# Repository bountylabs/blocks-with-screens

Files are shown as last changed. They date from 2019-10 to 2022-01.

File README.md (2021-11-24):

# Blocks With Screens

 

Block in its natural habitatAnimated 3d blockPuzzle-style block

It's Twitterversary blocks, but with screens and internet. Originally a Fall 2019 Twitter HackWeek project by [@johnboiles](https://github.com/johnboiles), [@magus](https://github.com/magus), [@mikeperiscope](https://github.com/mikeperiscope), [@seanfchan](https://github.com/seanfchan), and [@smartfuse](https://github.com/smartfuse).

## Assembly

### [**Click here to view assembly instructions on YouTube**](https://youtu.be/LxgdhXQPZw0)

<a href="https://youtu.be/LxgdhXQPZw0" target="_blank">
  assembly-video-thumbnail
</a>

Tips, notes & corrections:
* To protect the pins, we're shipping with two of the circuit boards attached to eachother. You'll need to separate these circuit boards before following the instructions above. Just gently pull them apart to separate them. They're hard to break :)
* Some of the boards may have small tabs protruding from the sides which may cause them not to fit in the wooden block. This is a byproduct of the manufacturing process. Clip these tabs off with nail clippers or wire clippers.
* Feel free to ask us on Twitter [@blkswithscreens](https://twitter.com/blkswithscreens) if you have any questions or problems!

## Components

### Blockware

This is the example software that you can run on the blocks. See [blockware/README.md](https://github.com/bountylabs/blocks-with-screens/blob/main/blockware/README.md) for installation instructions and a listing (with gifs!) of the available blockware.

### CAD

This contains the various design files building the block hardware. Most importantly, it contains the [Autodesk Eagle](https://www.autodesk.com/products/eagle/free-download) design files for the 3 PCBs that make up the block. See the [README.md](https://github.com/bountylabs/blocks-with-screens/blob/main/cad/pcb/README.md) in that directory for an overview of the responsibilities of the three different boards.

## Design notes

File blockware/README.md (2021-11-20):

# Blockware

A collection of programs meant to run on the blocks.

## Table of contents
- [Getting Started](#getting-started)
- [PlatformIO CLI](#using-the-platformio-cli)
- [Protips](#protips)
- [Demos](#demo-blockwares)

## Getting Started

All of these blockwares are configured to be compiled and uploaded using [PlatformIO](https://platformio.org/). You can probably also use the Arduino IDE or any other tool that works to compile and upload Arduino-compatible code with ESP8266 processors.

The easiest way to get started is using **[Visual Studio Code (VSCode)](https://code.visualstudio.com)** with the **[PlatformIO extension](https://platformio.org/install/ide?install=vscode)**.

1. Install **VSCode** either from the [website](https://code.visualstudio.com/) or (on macOS) using Homebrew `brew cask install visual-studio-code`.
    - **Windows Only** You may need to install drivers for your computer to be able to communicate with the block. [See below](#windows_drivers)
2. With VSCode open select **View -> Extensions** and search for `PlatformIO IDE`.
3. Click the extension and click **Install**.

    PlatformIO IDE Instructions

4. `File -> Open Workspace...` and select the `workspace.code-workspace` file in one of the blockware folders (e.g. `blockware/curvy-snake`)

    **_NOTE_**: In the workspace, you should have the **PlatformIO actions** available at the bottom of your VSCode

    VSCode PlatformIO Toolbar

  5. Connect your block to the computer using a Micro USB cable
  6. Turn it on using the switch in the back
  7. Press the **Upload** button (looks like a right arrow) in the Platform IO actions (bottom of your VSCode)

     NOTE: The program should compile and then upload to your block. It can also be handy to use the Serial Monitor to view any logs from the program that are output over the USB serial port.

     If the upload fails with an error message like `Error: Please specify upload_port for environment` or `Timed out waiting for packet header`, then you may need to edit the [`platformio.ini`](https://github.com/bountylabs/blocks-with-screens/blob/main/blockware/curvy-snake/platformio.ini) in the blockware's directory to set a specific `upload_port`. Look in `/dev/` for a `tty` device named something like `usbserial` or `ttyUSB` or `wchusbserial` and change `upload_port` to match the path to that device exactly.

  8. That's it, you should see the demo running on your block!

     For more info on using the PlatformIO VSCode extension check out the [PlatformIO Quick Start guide](https://docs.platformio.org/en/latest/integration/ide/vscode.html#quick-start).

## Using the PlatformIO CLI

You can alternately use the PlatformIO CLI if that's more your style. Follow one of the [installation methods on the PlatformIO site](https://platformio.org/install/cli). As of this writing, they recommend using their installer script:

```bash
python3 -c "$(curl -fsSL https://raw.githubusercontent.com/platformio/platformio/master/scripts/get-platformio.py)"
```

The script will probably instruct you to add something to your `PATH` in order to use the `pio` binary. Something like the following (which you could add to your `.bashrc` / `.zshrc`)

```bash
export PATH=$HOME/.platformio/penv/bin:$PATH
```

You can now build and upload blockware from the command line like this:

```bash
cd blockware/curvy-snake
pio run --target upload
```

Or if you want to override the `upload_port` (e.g. for blockwares that support WiFi OTA programming)

```bash
cd blockware/gif-download
pio run --target upload --upload-port gif-example.local
```

## Protips

#### Serial Monitor Reset

In the VSCode PlatformIO Serial Monitor, you can quickly restart the block by pressing `Ctrl-T Ctrl-D` twice. This toggles the `DTR` pin on the USB-serial chip and that pin is connected to the `RST` pin on the microcontroller.

#### Logging using `Dlog.h`

If using the `DLog` library for logging over the serial monitor or telnet you need to add `#define SERIALLOG 1` or `#define TELNETLOG 1` respectively before including `DLog.h` to enable serial logging. For example, for logging to the serial port:

```C
#define SERIALLOG 1
#include <DLog.h>
```

If using `TELNETLOG` then from your computer you can do something like the following to get the logs to your terminal over the network.

```bash
telnet homeassistant-display.local
```

#### Ensure PlatformIO is up to date

- Open the VSCode PlatformIO CLI (`⌘ + Shift + P` type `platformio cli` and press `Enter`)
- In the TERMINAL window at the bottom of VSCode, type in the command below

```sh
make update
```

Your PlatformIO dependencies should not all be up to date. Running the command again will report each at `[Up-to-date]` 🎉

## Demo Blockwares

This repo contains a handful of example blockwares you could run directly or use as a starting point to make your own blockware! Please share back any neat things you make so that others can benefit from it!

### Adafruit Example

adafruit-example

A fork of Adafruit's [SSD1351 OLED example code](https://github.com/adafruit/Adafruit-SSD1351-library/blob/master/examples/test/test.ino) with the `delay`s removed. Useful as an overview of the available graphics APIs in the Adafruit GFX library or as a graphics benchmark when tweaking the Adafruit GFX Library code.

### Bouncing Logo

Bouncing Logo

The most 90s-est demo we've got. Bounce the Twitter logo around your screen just like your DVD player did to prevent burn-in on your CRT TV in 1999.

### Curvy Snake

curvy-snake

It's kinda like those old pipes screensavers, or snake with curves. Watch randomly generated curves snake around your block's screen.

### Gif Download

Gif DownloadServer Interface

This demo shows a QR code that takes you to a web page where you can upload a gif, have it translated to a block-friendly format, then the block can download it and begin to display it.

Requires a Node.js-based server component which you can find in in the `gif-download/server` directory.

### Homeassistant Display

Home Assistant Display

An example of a program that can connect to a [Home Assistant](https://www.home-assistant.io/) home automation interface and display sensor values on the screen.

### JPEG Download Example

JPEG Download

An example that downloads a JPEG and displays it on the block.

### Pixel Dust

pixel-dust

An example that uses the [Adafruit Pixel Dust](https://github.com/adafruit/Adafruit_PixelDust) to create animated dust that interacts with the accelerometer and a static Twitter Logo.

### RGB LED

rgb-led

An example that uses the (normally not-included) internal RGB LED. This requires modification of the PCB by soldering on an RGB LED. This is probably not the blockware you're looking for.

### Snake

Snake introGameplayUser Interface

The game of snake! This demo creates a WiFi access point that you can connect to on your phone to control the snake.

### Stocks and Weather

Stocks and Weather

An example that downloads stocks and weather.

### Video Display

An example of real-time video streaming from your computer to your block.

<a href="https://twitter.com/samhaves/status/1177639088540635141">Blockware Live Video Demo</a>

### Windows Drivers

Since the PCB is compatible with a [Wemos D1 Mini](https://docs.wemos.cc/en/latest/d1/d1_mini.html) use the [following CH340 driver](https://docs.wemos.cc/en/latest/ch340_driver.html).
  
- With your block plugged in to your computer, find it in the device manager
  - Windows Device Manager
- Double click on the device
  - Windows USB Device
- Click on the Driver tab and choose Update Driver
  - Windows Driver Update
- Browse to where you downloaded and unzipped the driver
  - Browse for Driver
- Let Windows find the driver files within the folder or subfolder
  - Browse for Driver

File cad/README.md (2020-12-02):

# CAD Files

This contains the various design files for the mechanical components of the blocks.

## Parts List
* Assembled PCBs (See the README.md in the `pcb` directory in the repository for more details)
  * USB board
  * Microcontroller board
  * OLED board
* 1.5” SSD1351 128x128 OLED screen
* 240mAh 602025 LiPo battery with JST-SH connector
* Laser-cut wood “puzzle” blocks (5 separate pieces that fit together)
* Laser cut paper spacers (for friction fit and alignment)

## Components

### PCBs

The most important part of the block! The `pcb` directory contains the [Autodesk Eagle](https://www.autodesk.com/products/eagle/free-download) design files for the 3 PCBs that make up the block. See the [README.md](https://github.com/bountylabs/blocks-with-screens/blob/main/cad/pcb/README.md) in that directory for an overview of the responsibilities of the three different boards.

### Laser-cut Wood “Puzzle” Blocks

These are the laser-cuttable sides and back of the block. Since these need to fit together with only friction, the design may need to be adjusted based on the laser being used. Designs are included for a 0.23mm kerf laser as well as ones that worked well on @johnboiles's GlowForge. The `puzzleblock.f3d` (Fusion 360) file has the original designs.

### Laser-cut Paper Spacers

These help hold the PCBs inside the block and also helps center them inside the block. These should be cut out of 110 lb card stock paper. The laser width doesn’t matter here since paper bends.

### Block With Screen F3Z File

This Fusion 360 file has all of the components modeled in one place. Used mostly for neat visualizations like the assembly video. Also very useful to visualize the internal spacing when changing PCB components placements. This also contains the original design for the paper spacers.

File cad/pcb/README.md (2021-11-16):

# Blocks With Screens PCB Files

## Components

The blocks are made up of 3 components.

### OLED Board

OLED Back OLED Front

This board is responsible for all the circuitry to drive a SSD1351 OLED display. This design is heavily based on [Adafruit's breakout board](https://github.com/adafruit/Adafruit-1.5inch-Color-OLED-PCB) for the same display.

It consists of a 13V boost regulator to provide the required voltage to drive the OLED, as well as necessary passive components required by the OLED's datasheet.

### Microcontroller Board

Microcontroller Back Microcontroller Front

This board is a mounting point for the ESP12 microcontroller and the MMA8452Q 3-axis accelerometer. It also has unpopulated pads for a [SparkFun Qwiic](https://www.sparkfun.com/qwiic) connector and a WS2812B RGB LED if you want to add additional functionality.

### USB Board

USB Back USB Front

This board is responsible for:
* Providing a USB serial interface for programming the microcontroller (with automatic reset)
* Providing regulated 3.3V power to the Microcontroller and OLED
* Providing charging circuitry to charge the LiPo battery

This board is based on various Adafruit [LiPo charging boards](https://learn.adafruit.com/adafruit-pro-trinket-lipoly-slash-liion-backpack) and [USB powered boards](https://learn.adafruit.com/introducing-trinket/downloads) with the simplest (by part count) USB-serial chip we could find.

## PCB Hacking

We hope you'll open up your blocks and add new functionality or boards we never even dreamed of.

The pin layout is compatible with the [Wemos D1 Mini](https://docs.wemos.cc/en/latest/d1/d1_mini.html) (available on your usual internet shopping sites) so any shields made for those should work!

There is un unpopulated [SparkFun Qwiic](https://www.sparkfun.com/qwiic) connector on the microcontroller board. If you solder on a Qwiic connector (just a 4-pin JST connector) you can connect your board to any of the dozens of [Qwiic compatible peripherals](https://www.sparkfun.com/qwiic#products) (e.g. sensors, screens, GPS) out there.

There's an unpopulated spot on the Microcontroller board for a WS2812B RGB LED (or similar). This might come in handy if you want to, say, cut a window in the side of your block and trick it out with colors inside. Note that these LEDs will typically initialize to a random color so if you add the LED, but don't use it in your program, it will probably be lit up to a random color.

You could also add PCBs for different microcontrollers, different screens, or maybe even make a USB-C version! This was meant to be modular. Have fun, and share back what you build!

## Manufacturing Boards

We used [OshPark](https://oshpark.com/) for creating our prototype PCBs which we then soldered by hand or in a [reflow oven](https://github.com/UnifiedEngineering/T-962-improvements). We used [PCBWay](https://www.pcbway.com/) to mass manufacture assembled PCBs.

There's an included [script](https://github.com/bountylabs/blocks-with-screens/blob/main/pcb/eagle_to_pcbway.py) for exporting the Eagle PCB files in a bill-of-materials (BOM) format that PCBWay accepts.

## Changelog

### Microcontroller Board V4

* MMA8452QR1 accelerometers are #chipshortage'd. Switch to LIS2DW12

### OLED Board V5

* Revert the revert to go back to VIN for the 13V boost circuit as it didn't seem to have any effect. And this lightens the load on the 3.3V regulator. This is effectively the same design as OLED Board V3.

### USB Board V5

* Turn the battery connector counter-clockwise by 90 degrees to avoid wires hanging off the side of the board and not fitting in the block.

### OLED Board V4

* Revert back to using 3.3V for the 13V boost circuit to hopefully avoid issues I've seen twice now with the OLED screens developing bad vertical lines of pixels. This is what Adafruit does in their board; perhaps there's a reason for it.

### USB Board V4

* Use thicker (power) trace for 3.3V
* Make the USB side slots wider to comply with PCBWay
* Add a JST-SH connector (SM02B-SRSS-TB) for the battery

### Microcontroller Board V3

* Attach 3.3V to the ESP12 (doh!)

### OLED Board V3

* Uses `D4/GPIO2` for `OLED DC` instead of `D1/GPIO5` since that pin is I2C `SCK`.

### Microcontroller Board V2

* Fixed disconnected decoupling capacitor.
* Added optional header for MMA8452QR1 accelerometer.
* Added optional [Qwiic](https://www.sparkfun.com/qwiic) header for SparkFun accessories.
* Added optional [5050 NeoPixel](https://www.adafruit.com/product/1655) pad.

### USB Board V3

* Fix width of power trace going to the switch.

### OLED Board V2

* Uses `D1` for `OLED DC` instead of `D6` (`MISO`) so we don’t have to hack SPI.c for hardware SPI.
* Uses `VIN` for power for the 13V boost (possible this will reduce the flicker, especially during low battery).
* Removed the 3-pin SPI jumper since we didn’t use it.
* Move all the screen capacitors closer to the screen connector (even smaller chance of reducing flicker)

### USB Board V2

* Removed oscillator and move to using the `CH340C` instead of `CH340G` USB-UART chip.
* Connect `VCC` on the `CH340C` chip (fix error from V1).
* Move most parts to the front of the board for easier manufacturing.
* Add an optional on LED.
* Add pads for a switch.

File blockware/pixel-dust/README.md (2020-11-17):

# Pixel Dust

Demo that uses the onboard accelerometer along with [Adafruit's Pixel Dust library](https://github.com/adafruit/Adafruit_PixelDust) to generate a physics demo where particles move with the direction of gravity.

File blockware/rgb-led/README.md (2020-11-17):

# RGB LED Example

Very simple example that uses the (normally unpopulated) SK6812 LED on the Microcontroller board.

Note, this RGB LED *was not* included in the final assembly of the blocks, so this is only available for reference purposes for those brave enough to solder on their own internal RGB LED to the microcontroller board.

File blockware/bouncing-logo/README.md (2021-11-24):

# Bouncing Logo

Bouncing Twitter logo that cycles Twitter colors. Channels 1999 DVD player screensaver vibes

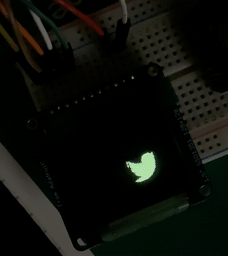
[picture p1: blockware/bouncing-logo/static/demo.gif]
Demo


## Inspiration

### Twitter color palette

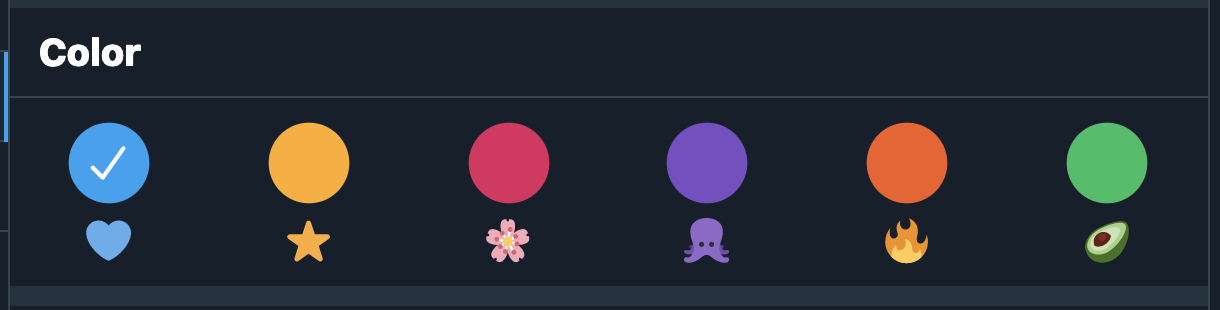
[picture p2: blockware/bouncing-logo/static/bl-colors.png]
ColorPalette


### Bouncing DVD logo concept

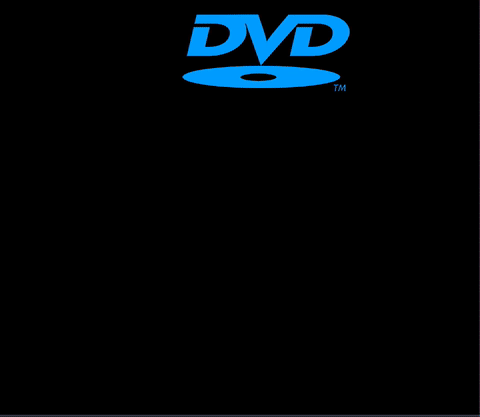
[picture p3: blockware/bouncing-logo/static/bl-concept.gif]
InspirationDVDAnimation


## VirtualBlox support

You can also run this blockware locally using VirtualBlox. Change the env in VSCode to VirtualBlox then hit 'upload'. Or use `pio run -e VirtualBlox -t upload` from the command line.



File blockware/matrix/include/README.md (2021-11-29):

# Why is this folder here?

`blockware/matrix/.vscode/c_cpp_properties.json` keeps including `"blockware/matrix/include",` in the `includePath` array under the `PlatformIO` entry in `configurations`. So we create it to get rid of an annoying error in VSCode

```
⚠️ Cannot find "/Users/noah/github/blocks-with-screens/blockware/matrix/include".
```

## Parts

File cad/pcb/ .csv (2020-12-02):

Part | Value | Device | Package | Description | MPN | POPULATE
C1 | 1.0uF | CAP_CERAMIC0805 | 0805 | Ceramic Capacitors | C0805C105K4RAC7210
C2 | 10uF/16V | CAP_CERAMIC0805 | 0805 | Ceramic Capacitors | EMK212ABJ106KG-T
C3 | 10uF | CAP_CERAMIC0805 | 0805 | Ceramic Capacitors | EMK212ABJ106KG-T
C4 | 10uF/16V | CAP_CERAMIC0805 | 0805 | Ceramic Capacitors | EMK212ABJ106KG-T
C5 | 1.0uF | CAP_CERAMIC0805 | 0805 | Ceramic Capacitors | C0805C105K4RAC7210
C6 | 10uF | CAP_CERAMIC0805 | 0805 | Ceramic Capacitors | EMK212ABJ106KG-T
C7 | 0.1uF | CAP_CERAMIC0805 | 0805 | Ceramic Capacitors | 08051C104J4T4A
D1 | 1N4148 | DIODESOD-323 | SOD-323 | Diode | 1N4148WS-E3-08
D2 | 1N4148 | DIODESOD-323 | SOD-323 | Diode | 1N4148WS-E3-08
D3 | BAT54T1G | DIODESOD-123 | SOD-123 | Diode | BAT54T1G
JP1 |  | PINHD-1X8CLEANBIG | 1X08-CLEANBIG | PIN HEADER | 10129378-908001BLF | 0
JP2 |  | PINHD-1X8CLEANBIG | 1X08-CLEANBIG | PIN HEADER | 10129378-908001BLF | 0
L1 | 10uH | INDUCTOR | INDUCTOR_1007 | Inductors | L0805R100MPWRT
R1 | 10K | R-US_R0805 | R0805 | RESISTOR, American symbol | CRCW080510K0FKEAC
R2 | 600K | R-US_R0805 | R0805 | RESISTOR, American symbol | ERJ-6ENF5903V
R3 | 50 | R-US_R0805 | R0805 | RESISTOR, American symbol | CRCW080550R0FKTA
R4 | 100K | R-US_R0805 | R0805 | RESISTOR, American symbol | CR0805AFX-1003EAS
R5 | 10K | R-US_R0805 | R0805 | RESISTOR, American symbol | CRCW080510K0FKEAC
U1 | UG-2828GDEDF11 | DISP_OLED_UG-2828GDEDF11TOP | FPC_XF2M-3015-1A | 128x128 1.5 RGB OLED - UG-2828GDEDF11" | XF2M-3015-1A
U2 | FAN5331SX | FAN5331 | SOT23-5@1 | FAN5331 - LED/OLED 20V Boost Converter | FAN5331SX

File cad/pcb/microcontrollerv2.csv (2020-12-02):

Part | Value | Device | Package | Description | MPN | POPULATE
C1 | 10uF | C-USC0805 | C0805 | CAPACITOR, American symbol | EMK212ABJ106KG-T
C2 | .1uF | C-USC0805 | C0805 | CAPACITOR, American symbol | 08051C104J4T4A
C3 | 10uF | C-USC0805 | C0805 | CAPACITOR, American symbol | EMK212ABJ106KG-T | 0
C4 | .1uF | C-USC0805 | C0805 | CAPACITOR, American symbol | 08051C104J4T4A | 0
J1 | SMD | I2C_STANDARDJS-1MM | 1X04_1MM_RA | SparkFun I2C Standard Pinout Header | PRT-14417 | 0
JP1 |  | PINHD-1X8CLEANBIG | 1X08-CLEANBIG | PIN HEADER | 8Fx1L-254mm
JP2 |  | PINHD-1X8CLEANBIG | 1X08-CLEANBIG | PIN HEADER | 8Fx1L-254mm
LED1 | WS2812B5050 | WS2812B5050 | WS2812B |  | 1655 | 0
R1 | 10K | R-US_R0805 | R0805 | RESISTOR, American symbol | CRCW080510K0FKEAC
R2 | 10K | R-US_R0805 | R0805 | RESISTOR, American symbol | CRCW080510K0FKEAC
R3 | 10K | R-US_R0805 | R0805 | RESISTOR, American symbol | CRCW080510K0FKEAC
R4 | 10K | R-US_R0805 | R0805 | RESISTOR, American symbol | CRCW080510K0FKEAC
U1 | MMA8452Q | MMA8452Q | QFN-16_0.5MM | MMA8452Q 3-Axis, 12/8-bit Digital Accelerometer | MMA8452QR1 | 0
X1 |  | ESP-12 | ESP-12 |  | ESP12

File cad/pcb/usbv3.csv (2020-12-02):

Part | Value | Device | Package | Description | MPN | PROD_ID | SF_ID | VALUE
C1 | 10µF | C-USC0805 | C0805 | CAPACITOR, American symbol | EMK212ABJ106KG-T
C2 | 10uF | C-USC0805 | C0805 | CAPACITOR, American symbol | EMK212ABJ106KG-T
C3 | 10µF | C-USC0805 | C0805 | CAPACITOR, American symbol | EMK212ABJ106KG-T
C4 | 1.0uF | 1.0UF-0805-25V-10% | 0805 | 1µF ceramic capacitors | C0805C105K4RAC7210 | CAP-08064 |  | 1.0uF
C5 | 0.1uF | 1.0UF-0805-25V-10% | 0805 | 1µF ceramic capacitors | 08051C104J4T4A | CAP-08064 |  | 1.0uF
CHG | RED | LED0805_NOOUTLINE | CHIPLED_0805_NOOUTLINE | LED | SMLD12E3N1WT86
D1 | MBR120 | DIODE-SCHOTTKYSOD-123 | SOD-123 |  | MBR120ESFT1G
J1 | JSTPH | CONN_02 | 1X02 | Multi connection point. Often used as Generic Header-pin footprint for 0.1 inch spaced/style header connections
J2 |  | 614105150621 | 614105150621 | WR-COM_USB_Micro Type AB_Vertical_THT, | 614105150621
JP1 |  | PINHD-1X8CLEANBIG | 1X08-CLEANBIG | PIN HEADER | 8Fx1L-254mm
JP2 |  | PINHD-1X8CLEANBIG | 1X08-CLEANBIG | PIN HEADER | 8Fx1L-254mm
ON | RED | LED0805_NOOUTLINE | CHIPLED_0805_NOOUTLINE | LED | SMLEN3WBC8W1
Q1 | ZXMP6A13FTA | MOSFET-P | SOT23-R | P-Channel Mosfet | ZXMP6A13FTA
Q2 | mmbt2222 | TRANSISTOR_NPNSOT23-3 | SOT23-3 | Transistor NPN | MMBT2222A-G
Q3 | mmbt2222 | TRANSISTOR_NPNSOT23-3 | SOT23-3 | Transistor NPN | MMBT2222A-G
R1 | 100K | R-US_R0805 | R0805 | RESISTOR, American symbol | CR0805AFX-1003EAS
R2 | 1K | R-US_R0805 | R0805 | RESISTOR, American symbol | ESR10EZPJ102
R3 | 10K\ | R-US_R0805 | R0805 | RESISTOR, American symbol | CRCW080510K0FKEAC
R4 | 1K | R-US_R0805 | R0805 | RESISTOR, American symbol | ESR10EZPJ102
R5 | 10K | R-US_R0603 | R0603 | RESISTOR, American symbol | CRCW080510K0FKEAC
R6 | 10K | R-US_R0603 | R0603 | RESISTOR, American symbol | CRCW080510K0FKEAC
S1 |  | SWITCH-SPDT-SMD-AYZ0202 | SWITCH_DPDT_SMD_AYZ0202 | Single Pole, Double Throw (SPDT) Switch | AYZ0202AGRLC | SWCH-08179 | COM-00597
U1 | MIC5225-3.3v | VREG_SOT23-5 | SOT23-5 | SOT23-5 Fixed Voltage Regulators | MIC5225-3.3YM5-TR
U2 | CH340C | CH340C | SO016 |  | CH340C | IC-14038
U3 | MCP73831T-2ACI/OT | MCP73831/OT | SOT23-5L | MCP73831/2 | MCP73831T-2ACI/OT

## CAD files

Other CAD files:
cad/puzzleblock.f3d

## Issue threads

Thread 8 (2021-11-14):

Windows driver installation instructions

leeaustinadams, 2021-11-14:
Although I mainly use Linux, I was messing around on my Windows 10 laptop and noticed some drivers are needed for communication with the board. I'll put a pull request together to add instructions.

johnboiles, 2021-11-16:
Oooh that will be awesome, thanks!!

Closed 2021-11-17.

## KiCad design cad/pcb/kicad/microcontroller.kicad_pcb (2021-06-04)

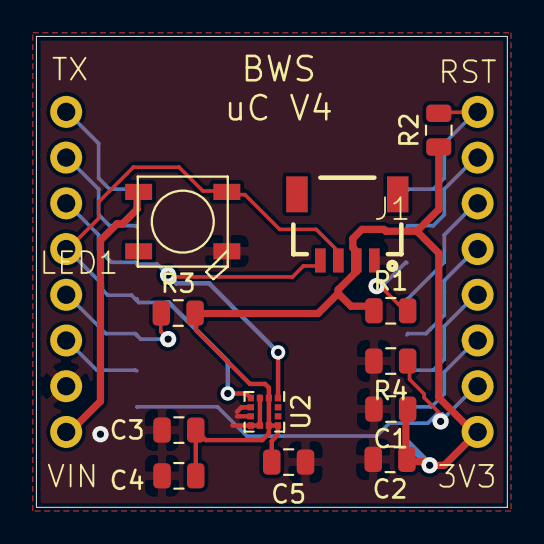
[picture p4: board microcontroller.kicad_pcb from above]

Board: 2 copper layers, 26.2 x 26.2 mm, 15 parts (0 on the bottom side), 17 nets.

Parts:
C1, C4: 10uF; C_0805_2012Metric
C2: .1uF; C_0805_2012Metric
C3, C5: 100nF; C_0805_2012Metric
J1: SMD; 1X04_1MM_RA
JP1, JP2: PINHD-1X8CLEANBIG; 1X08-CLEANBIG
LED1: WS2812B5050; WS2812B
R1, R2, R3, R4: 10K; R_0805_2012Metric
U2: LIS2DW12; LGA-12_2x2mm_P0.5mm
X1: ESP-12

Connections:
3.3V: C1.1, C2.1, C3.2, C4.2, C5.1, J1.2, JP2.1, R1.1, R2.1, R3.2, U2.2, U2.9, U2.10, X1.8
/A0: JP2.7, X1.2
/CH_PD: R1.2, X1.3
/D0/GPIO16: JP2.6, X1.4
/D1/GPIO5/SCL: J1.4, JP1.3, U2.1, X1.14
/D2/GPIO4/SDA: J1.3, JP1.4, LED1.4-DIN, U2.4, X1.13
/D3/GPIO0: JP1.5, R3.1, X1.12
/D4/GPIO2: JP1.6, X1.11
/D5/GPIO14/SCK: JP2.5, X1.5
/D6/GPIO12/MISO: JP2.4, X1.6
/D7/GPIO13/MOSI: JP2.3, X1.7
/D8/GPIO15: JP2.2, R4.1, X1.10
/RESET: JP2.8, R2.2, X1.1
/RX: JP1.2, X1.15
/TX: JP1.1, X1.16
GND: C1.2, C2.2, C3.1, C4.1, C5.2, J1.1, JP1.7, LED1.3-GND, R4.2, U2.3, U2.5, U2.6, U2.7, U2.8, X1.9
VIN: JP1.8, LED1.1-VDD

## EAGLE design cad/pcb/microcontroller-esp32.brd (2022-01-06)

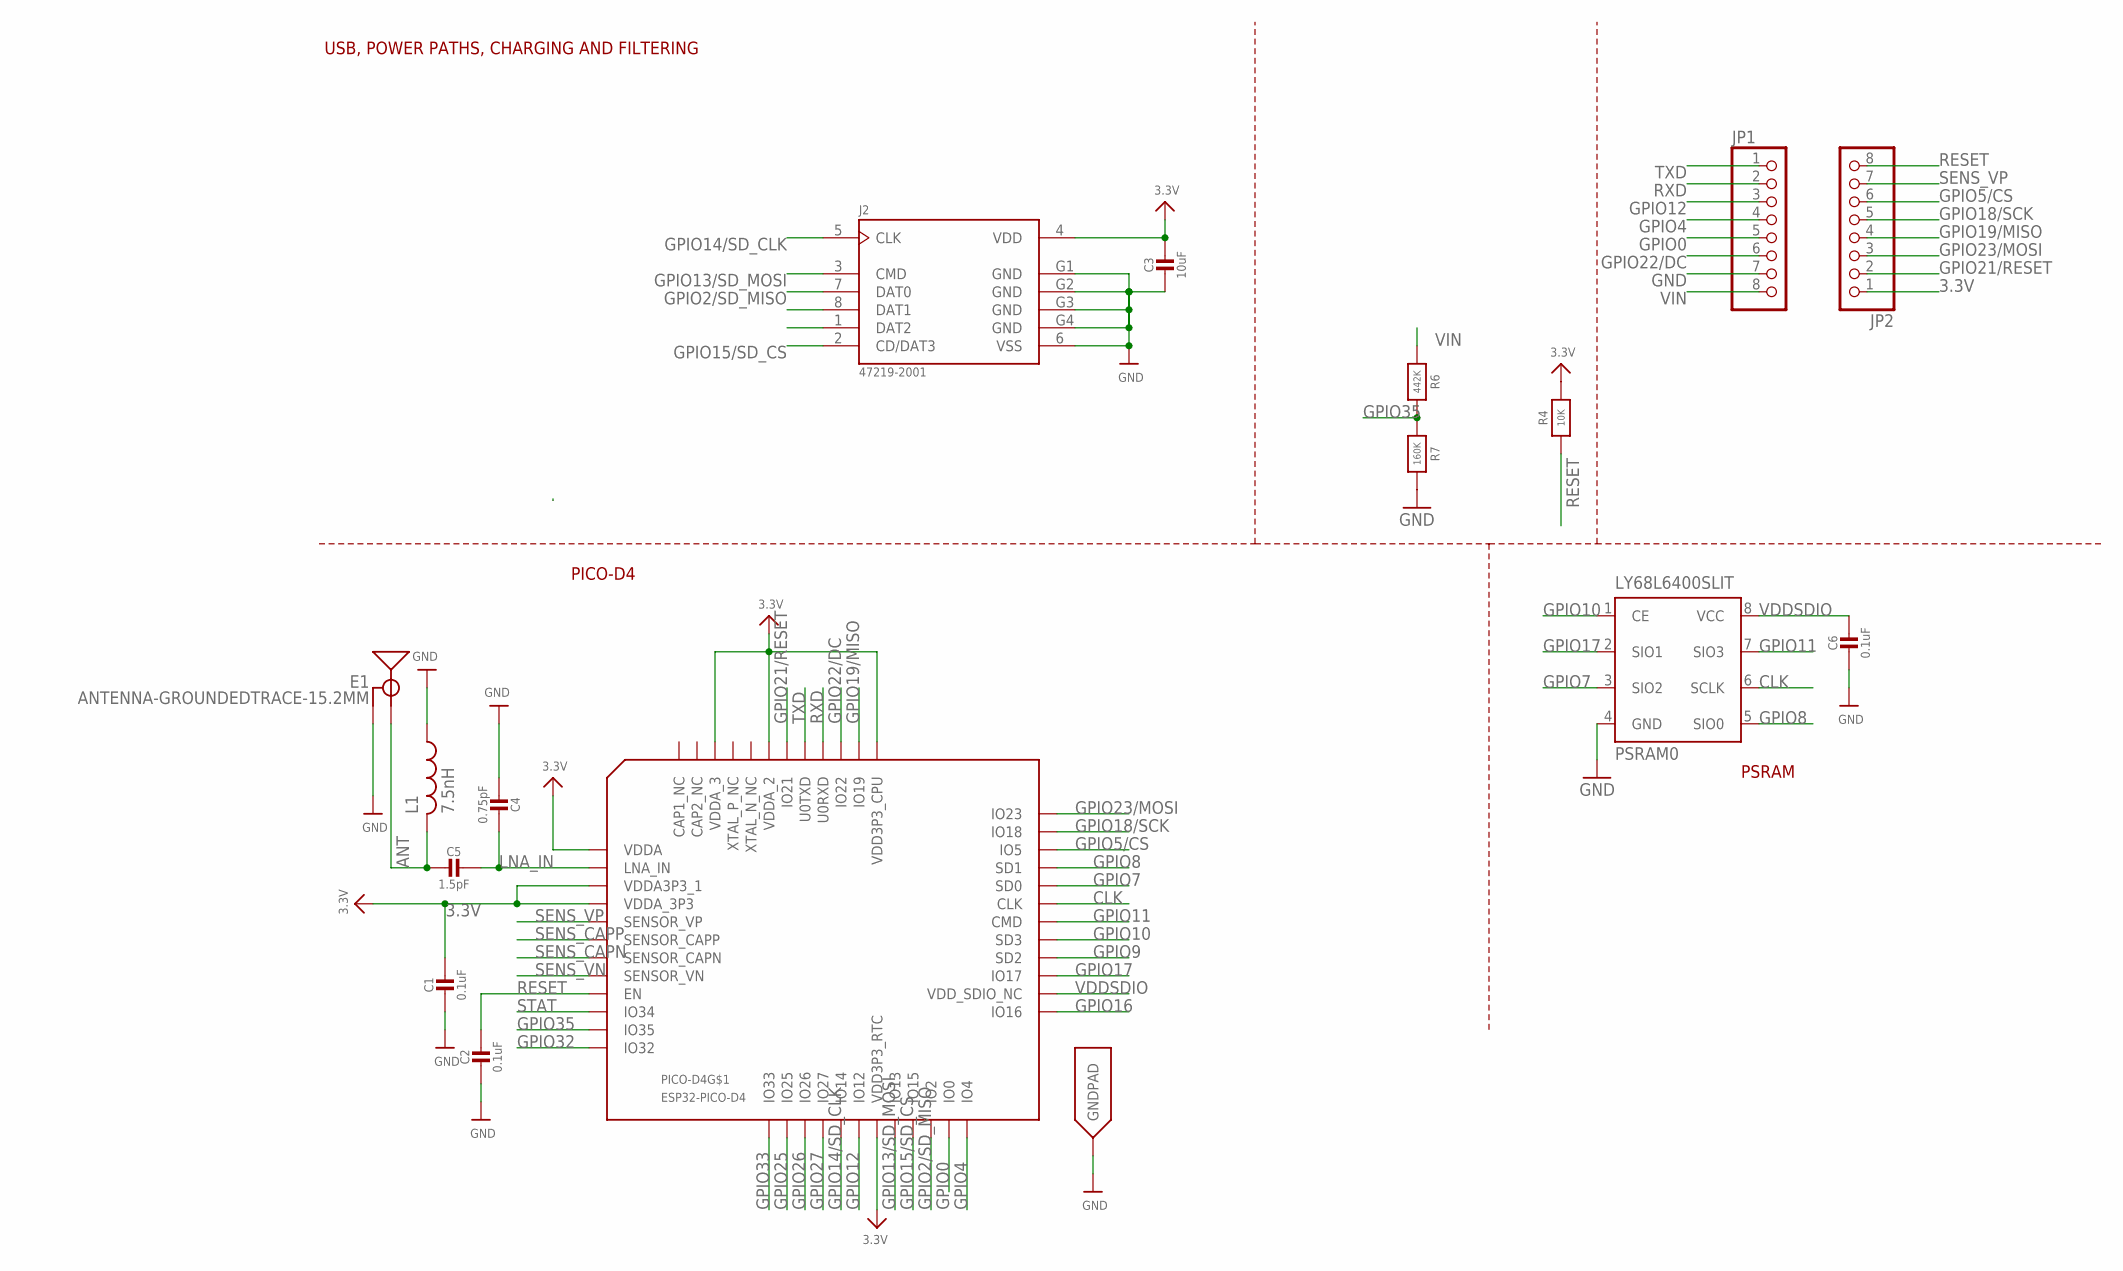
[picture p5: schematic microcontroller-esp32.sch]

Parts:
C1, C2, C6: 0.1uF; _0402MP
C3: 10uF; _0402MP
C4: 0.75pF; _0402MP
C5: 1.5pF; _0402MP
E1: ANTENNA-GROUNDEDTRACE-15.2MM; TRACE_ANTENNA_2.4GHZ_15.2MM
J2: 47219-2001; MOLEX_47219-2001
JP1, JP2: PINHD-1X8CLEANBIG; 1X08-CLEANBIG; MPN 83-15410
L1: 7.5nH; RESC0402_N
LY68L6400SLIT: PSRAM0; SOP8
PICO-D4: ESP32-PICO-D4; PICO-D4-QFN48
R4: 10K; _0402MP
R6: 442K; _0402MP
R7: 160K; _0402MP

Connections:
3.3V: C1.1, C3.1, J2.4 (VDD), JP2.1, PICO-D4.1 (VDDA), PICO-D4.3 (VDDA3P3_1), PICO-D4.4 (VDDA_3P3), PICO-D4.19 (VDD3P3_RTC), PICO-D4.37 (VDD3P3_CPU), PICO-D4.43 (VDDA_2), PICO-D4.46 (VDDA_3), R4.2
ANT: C5.2, E1.ANT (SIGNAL), L1.2
CLK: LY68L6400SLIT.6 (SCLK), PICO-D4.31 (CLK)
GND: C1.2, C2.2, C3.2, C4.2, C6.2, E1.GND, J2.6 (VSS), J2.G1 (GND), J2.G2 (GND), J2.G3 (GND), J2.G4 (GND), JP1.7, L1.1, LY68L6400SLIT.4 (GND), PICO-D4.EXP (GNDPAD), R7.2
GPIO0: JP1.5, PICO-D4.23 (IO0)
GPIO2/SD_MISO: J2.7 (DAT0), PICO-D4.22 (IO2)
GPIO4: JP1.4, PICO-D4.24 (IO4)
GPIO5/CS: JP2.6, PICO-D4.34 (IO5)
GPIO7: LY68L6400SLIT.3 (SIO2), PICO-D4.32 (SD0)
GPIO8: LY68L6400SLIT.5 (SIO0), PICO-D4.33 (SD1)
GPIO9: PICO-D4.28 (SD2)
GPIO10: LY68L6400SLIT.1 (CE), PICO-D4.29 (SD3)
GPIO11: LY68L6400SLIT.7 (SIO3), PICO-D4.30 (CMD)
GPIO12: JP1.3, PICO-D4.18 (IO12)
GPIO13/SD_MOSI: J2.3 (CMD), PICO-D4.20 (IO13)
GPIO14/SD_CLK: J2.5 (CLK), PICO-D4.17 (IO14)
GPIO15/SD_CS: J2.2 (CD/DAT3), PICO-D4.21 (IO15)
GPIO16: PICO-D4.25 (IO16)
GPIO17: LY68L6400SLIT.2 (SIO1), PICO-D4.27 (IO17)
GPIO18/SCK: JP2.5, PICO-D4.35 (IO18)
GPIO19/MISO: JP2.4, PICO-D4.38 (IO19)
GPIO21/RESET: JP2.2, PICO-D4.42 (IO21)
GPIO22/DC: JP1.6, PICO-D4.39 (IO22)
GPIO23/MOSI: JP2.3, PICO-D4.36 (IO23)
GPIO25: PICO-D4.14 (IO25)
GPIO26: PICO-D4.15 (IO26)
GPIO27: PICO-D4.16 (IO27)
GPIO32: PICO-D4.12 (IO32)
GPIO33: PICO-D4.13 (IO33)
GPIO35: PICO-D4.11 (IO35), R6.2, R7.1
LNA_IN: C4.1, C5.1, PICO-D4.2 (LNA_IN)
RESET: C2.1, JP2.8, PICO-D4.9 (EN), R4.1
RXD: JP1.2, PICO-D4.40 (U0RXD)
SENS_CAPN: PICO-D4.7 (SENSOR_CAPN)
SENS_CAPP: PICO-D4.6 (SENSOR_CAPP)
SENS_VN: PICO-D4.8 (SENSOR_VN)
SENS_VP: JP2.7, PICO-D4.5 (SENSOR_VP)
STAT: PICO-D4.10 (IO34)
TXD: JP1.1, PICO-D4.41 (U0TXD)
VDDSDIO: C6.1, LY68L6400SLIT.8 (VCC), PICO-D4.26 (VDD_SDIO_NC)
VIN: JP1.8, R6.1

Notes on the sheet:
USB, POWER PATHS, CHARGING AND FILTERING
PICO-D4
PSRAM

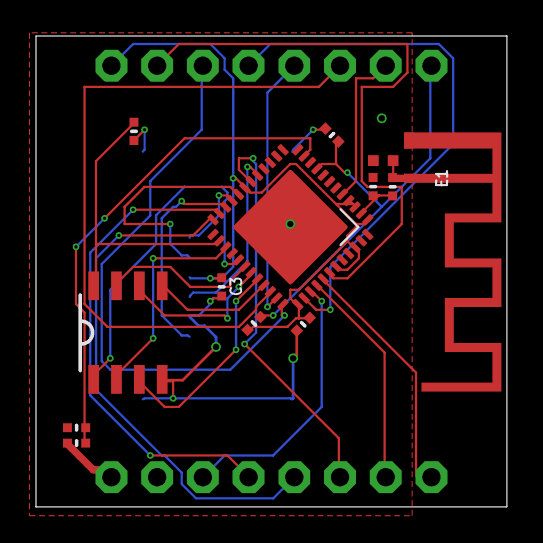
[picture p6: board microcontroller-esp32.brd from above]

Board: 4 copper layers, 26.2 x 26.2 mm, 16 parts (1 on the bottom side), 30 nets.

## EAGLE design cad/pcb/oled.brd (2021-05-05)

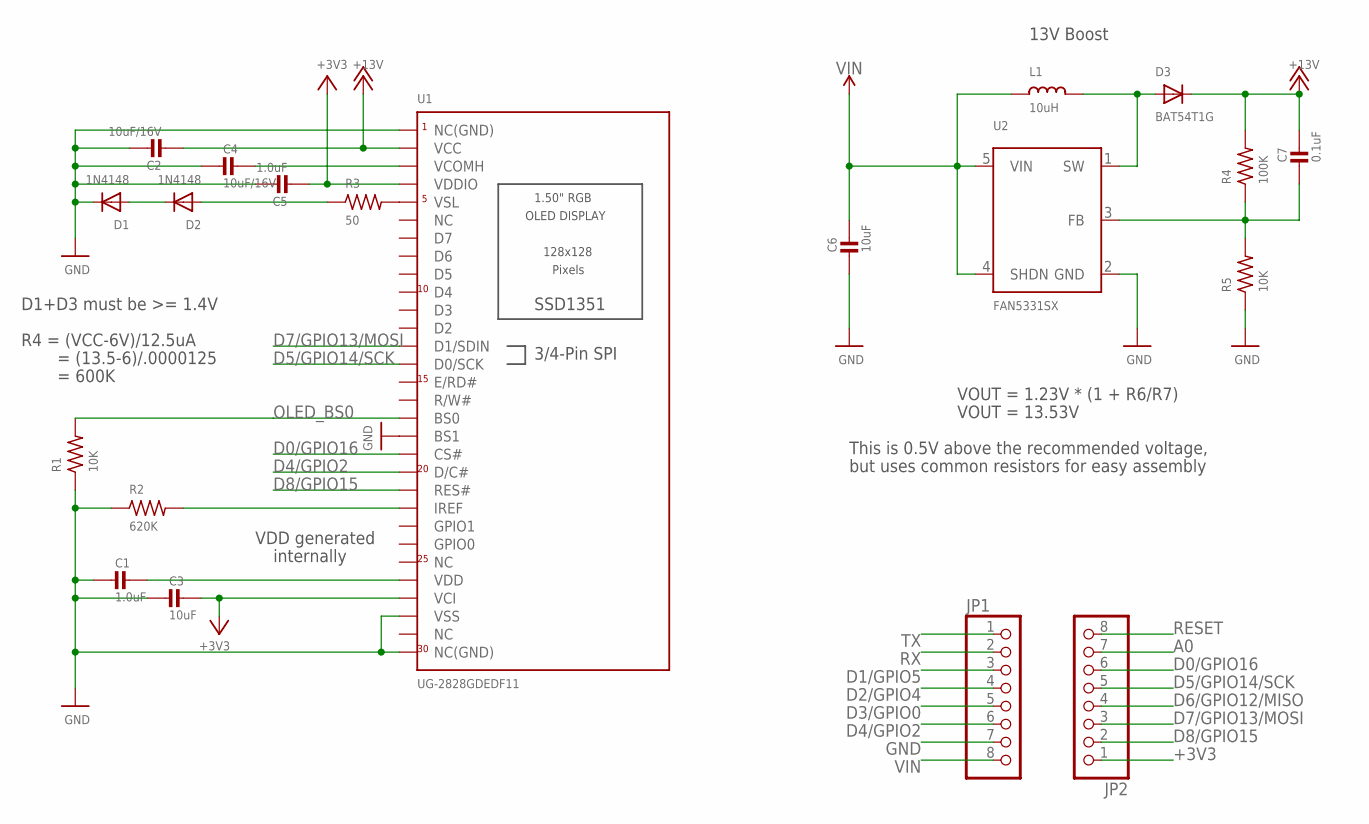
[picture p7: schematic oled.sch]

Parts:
C1, C5: 1.0uF; 0805; MPN C0805C105K4RAC7210
C2, C4: 10uF/16V; 0805; MPN CL21A106KOQNNNE
C3, C6: 10uF; 0805; MPN CL21A106KOQNNNE
C7: 0.1uF; 0805; MPN C0805C104M3RACTU
D1, D2: 1N4148; SOD-323; MPN 1N4148WS-E3-08
D3: BAT54T1G; SOD-123; MPN BAT54T1G
JP1, JP2: PINHD-1X8CLEANBIG; 1X08-CLEANBIG; MPN C124381
L1: 10uH; INDUCTOR_1007; MPN L0805R100MPWRT
R1, R5: 10K; R0805; MPN CRCW080510K0FKEAC
R2: 620K; R0805; MPN 0805W8F6203T5E
R3: 50; R0805; MPN CRCW080550R0FKTA
R4: 100K; R0805; MPN CR0805AFX-1003EAS
U1: UG-2828GDEDF11; FPC_XF2M-3015-1A; MPN XF2M-3015-1A
U2: FAN5331SX; SOT23-5@1; MPN FAN5331SX

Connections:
13V: C2.2, C7.1, D3.C, R4.2, U1.P$29 (VCC)
+3V3: C3.1, C5.2, JP2.1, U1.P$4 (VCI), U1.P$27 (VDDIO)
A0: JP2.7
D0/GPIO16: JP2.6, U1.P$12 (CS#)
D1/GPIO5: JP1.3
D2/GPIO4: JP1.4
D3/GPIO0: JP1.5
D4/GPIO2: JP1.6, U1.P$11 (D/C#)
D5/GPIO14/SCK: JP2.5, U1.P$17 (D0/SCK)
D6/GPIO12/MISO: JP2.4
D7/GPIO13/MOSI: JP2.3, U1.P$18 (D1/SDIN)
D8/GPIO15: JP2.2, U1.P$10 (RES#)
GND: C1.2, C2.1, C3.2, C4.2, C5.1, C6.2, D1.C, JP1.7, R1.1, R2.1, R5.1, U1.P$1 (NC(GND)), U1.P$3 (VSS), U1.P$13 (BS1), U1.P$30 (NC(GND)), U2.2 (GND)
IREF: R2.2, U1.P$9 (IREF)
unnamed: C1.1, U1.P$5 (VDD)
unnamed: D3.A, L1.P$2 (2), U2.1 (SW)
unnamed: R3.2, U1.P$26 (VSL)
unnamed: D2.A, R3.1
unnamed: C7.2, R4.1, R5.2, U2.3 (FB)
unnamed: D1.A, D2.C
OLED_BS0: R1.2, U1.P$14 (BS0)
RESET: JP2.8
RX: JP1.2
TX: JP1.1
VCOMH: C4.1, U1.P$28 (VCOMH)
VIN: C6.1, JP1.8, L1.P$1 (1), U2.4 (SHDN), U2.5 (VIN)

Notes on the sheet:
VOUT = 1.23V * (1 + R6/R7)
VOUT = 13.53V
This is 0.5V above the recommended voltage,
but uses common resistors for easy assembly
13V Boost
R4 = (VCC-6V)/12.5uA
= (13.5-6)/.0000125
= 600K
D1+D3 must be >= 1.4V
VDD generated
internally

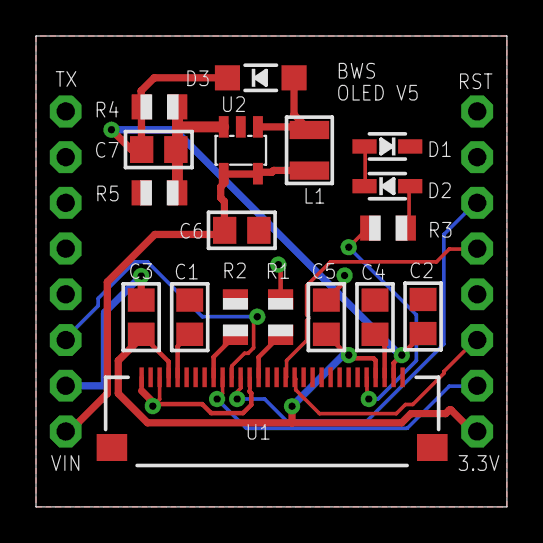
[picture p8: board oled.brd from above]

Board: 2 copper layers, 26.2 x 26.2 mm, 21 parts (1 on the bottom side), 18 nets.

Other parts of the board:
U$1: TWITTER5MM

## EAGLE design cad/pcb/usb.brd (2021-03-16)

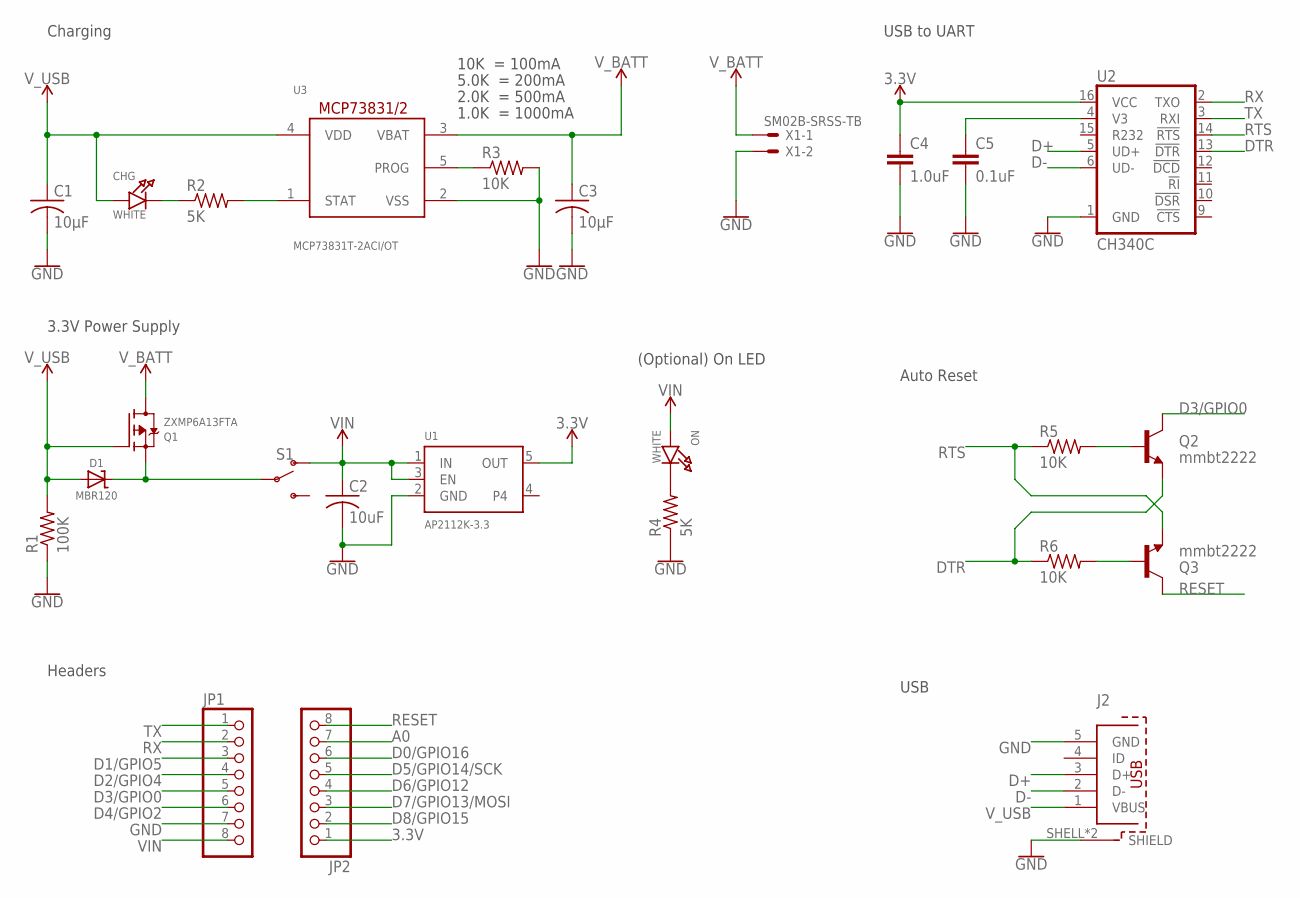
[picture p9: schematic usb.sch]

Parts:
C1, C3: 10µF; C0805; MPN CL21A106KPFNNNE
C2: 10uF; C0805; MPN CL21A106KPFNNNE
C4: 1.0uF; 0805; MPN C0805C105K4RAC7210
C5: 0.1uF; 0805; MPN C0805C104M3RACTU
CHG: WHITE; CHIPLED_0805_NOOUTLINE; MPN NCD0805W2
D1: MBR120; SOD-123; MPN MBR120ESFT1G
J2: 614105150621; MPN U-D-M5DD-W-1
JP1, JP2: PINHD-1X8CLEANBIG; 1X08-CLEANBIG; MPN C27438
ON: WHITE; CHIPLED_0805_NOOUTLINE; MPN NCD0805W2
Q1: ZXMP6A13FTA; SOT23-R; MPN ZXMP6A13FTA
Q2, Q3: mmbt2222; SOT23-3; MPN MMBT2222A-G
R1: 100K; R0805; MPN 0805W8F1003T5E
R2, R4: 5K; R0805; MPN 0805W8F4871T5E
R3: 10K; R0805; MPN CRCW080510K0FKEAC
R5, R6: 10K; R0603; MPN RC0603FR-0710KL
S1: SWITCH-SPDT-SMD-AYZ0202; SWITCH_DPDT_SMD_AYZ0202; MPN AYZ0202AGRLC
U1: AP2112K-3.3; SOT23-5; MPN AP2112K-3.3
U2: CH340C; SO016; MPN CH340C
U3: MCP73831T-2ACI/OT; SOT23-5L; MPN MCP73831T-2ACI/OT
X1: SM02B-SRSS-TB; MPN SM02B-SRSS-TB

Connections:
3.3V: C4.1, JP2.1, U1.5 (OUT), U2.16 (VCC)
A0: JP2.7
D0/GPIO16: JP2.6
D1/GPIO5: JP1.3
D2/GPIO4: JP1.4
D3/GPIO0: JP1.5, Q2.3 (C)
D4/GPIO2: JP1.6
D5/GPIO14/SCK: JP2.5
D6/GPIO12: JP2.4
D7/GPIO13/MOSI: JP2.3
D8/GPIO15: JP2.2
D+: J2.3 (D+), U2.5 (UD+)
D-: J2.2 (D-), U2.6 (UD-)
DTR: Q2.2 (E), R6.1, U2.13 (!DTR)
GND: C1.2, C2.2, C3.2, C4.2, C5.2, J2.5 (GND), J2.SHELL (SHIELD), J2.SHELL1 (SHIELD), JP1.7, R1.1, R3.2, R4.1, U1.2 (GND), U2.1 (GND), U3.2 (VSS), X1.2
unnamed: CHG.C, R2.1
unnamed: C5.1, U2.4 (V3)
unnamed: ON.C, R4.2
unnamed: R2.2, U3.1 (STAT)
unnamed: D1.C, Q1.2 (S), S1.5
unnamed: R3.1, U3.5 (PROG)
unnamed: Q3.1 (B), R6.2
unnamed: Q2.1 (B), R5.2
RESET: JP2.8, Q3.3 (C)
RTS: Q3.2 (E), R5.1, U2.14 (!RTS)
RX: JP1.2, U2.2 (TXO)
TX: JP1.1, U2.3 (RXI)
VIN: C2.1, JP1.8, ON.A, S1.6 (O), U1.1 (IN), U1.3 (EN)
V_BATT: C3.1, Q1.3 (D), U3.3 (VBAT), X1.1
V_USB: C1.1, CHG.A, D1.A, J2.1 (VBUS), Q1.1 (G), R1.2, U3.4 (VDD)

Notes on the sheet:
10K = 100mA
5.0K = 200mA
2.0K = 500mA
1.0K = 1000mA
Charging
3.3V Power Supply
Headers
USB to UART
Auto Reset
USB
(Optional) On LED

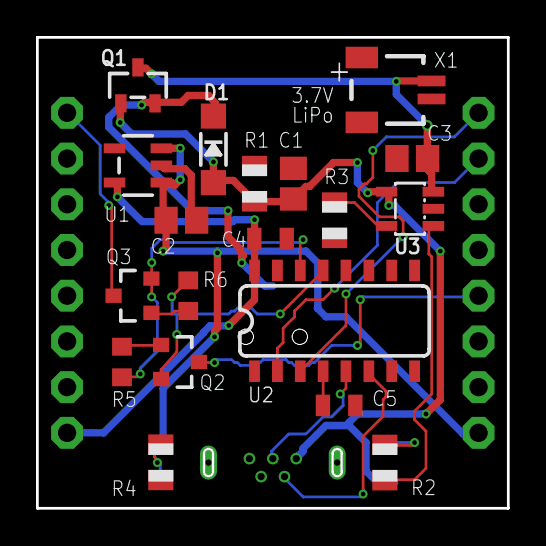
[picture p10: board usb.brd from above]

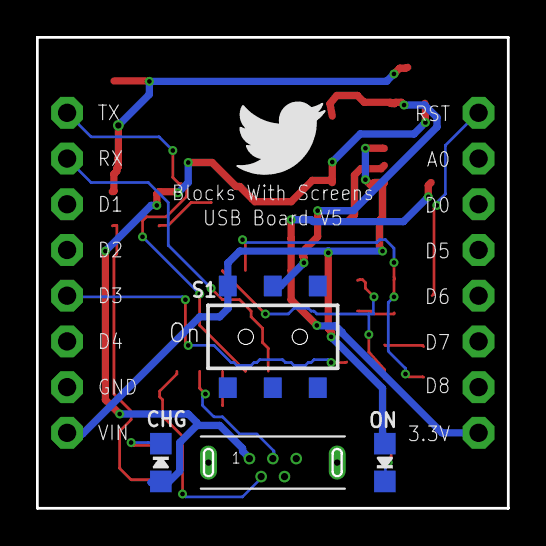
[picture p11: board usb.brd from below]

Board: 2 copper layers, 26.2 x 26.2 mm, 26 parts (5 on the bottom side), 21 nets.

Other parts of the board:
U$1: TWITTER5MM

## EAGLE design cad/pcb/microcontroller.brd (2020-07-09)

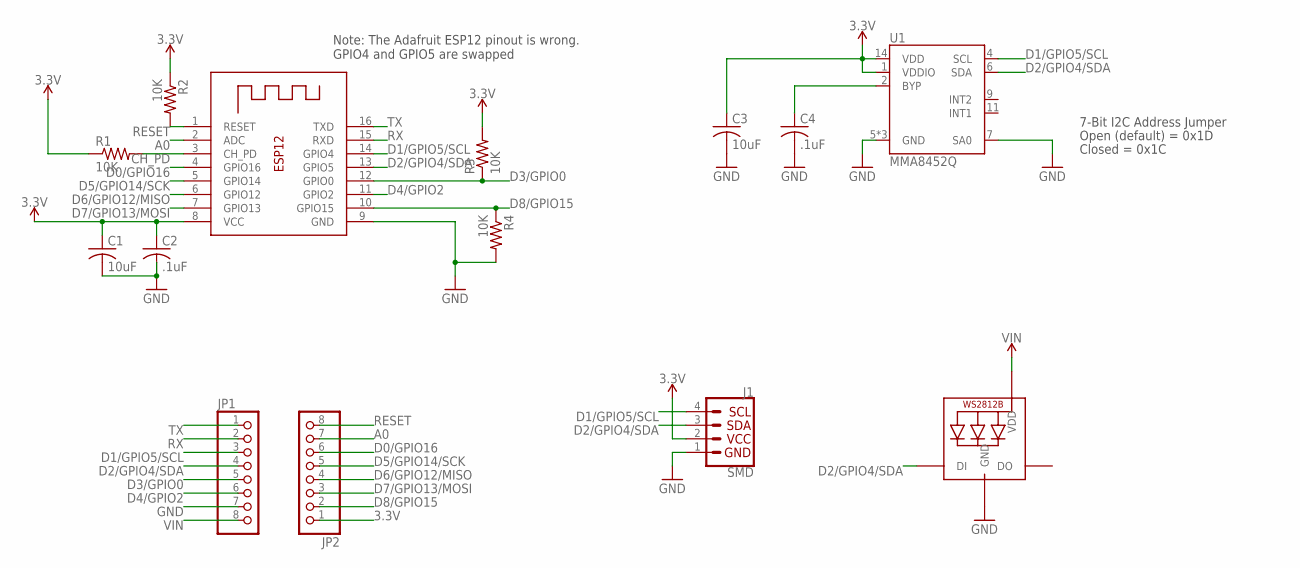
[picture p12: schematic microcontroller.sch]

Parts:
C1, C3: 10uF; C0805; MPN LMK212BJ106KG-T
C2, C4: .1uF; C0805; MPN C0805C104M3RACTU
J1: SMD; 1X04_1MM_RA; MPN PRT-14417
JP1, JP2: PINHD-1X8CLEANBIG; 1X08-CLEANBIG; MPN 83-15410
LED1: WS2812B5050; WS2812B; MPN 1655
R1, R2, R3, R4: 10K; R0805; MPN CRCW080510K0FKEAC
U1: MMA8452Q; QFN-16_0.5MM; MPN MMA8452QR1
X1: ESP-12; MPN ESP-12F(ESP8266MOD)

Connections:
3.3V: C1.1, C2.1, C3.1, J1.2 (VCC), JP2.1, R1.1, R2.1, R3.2, U1.1 (VDDIO), U1.14 (VDD), X1.8 (VCC)
A0: JP2.7, X1.2 (ADC)
BYP: C4.1, U1.2 (BYP)
CH_PD: R1.2, X1.3 (CH_PD)
D0/GPIO16: JP2.6, X1.4 (GPIO16)
D1/GPIO5/SCL: J1.4 (SCL), JP1.3, U1.4 (SCL), X1.14 (GPIO4)
D2/GPIO4/SDA: J1.3 (SDA), JP1.4, LED1.4-DIN (DI), U1.6 (SDA), X1.13 (GPIO5)
D3/GPIO0: JP1.5, R3.1, X1.12 (GPIO0)
D4/GPIO2: JP1.6, X1.11 (GPIO2)
D5/GPIO14/SCK: JP2.5, X1.5 (GPIO14)
D6/GPIO12/MISO: JP2.4, X1.6 (GPIO12)
D7/GPIO13/MOSI: JP2.3, X1.7 (GPIO13)
D8/GPIO15: JP2.2, R4.1, X1.10 (GPIO15)
GND: C1.2, C2.2, C3.2, C4.2, J1.1 (GND), JP1.7, LED1.3-GND (GND), R4.2, U1.5 (GND), U1.7 (SA0), U1.10 (GND), U1.12 (GND), X1.9 (GND)
RESET: JP2.8, R2.2, X1.1 (RESET)
RX: JP1.2, X1.15 (RXD)
TX: JP1.1, X1.16 (TXD)
VIN: JP1.8, LED1.1-VDD (VDD)

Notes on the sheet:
7-Bit I2C Address Jumper
Closed = 0x1C
Open (default) = 0x1D
Note: The Adafruit ESP12 pinout is wrong. GPIO4 and GPIO5 are swapped

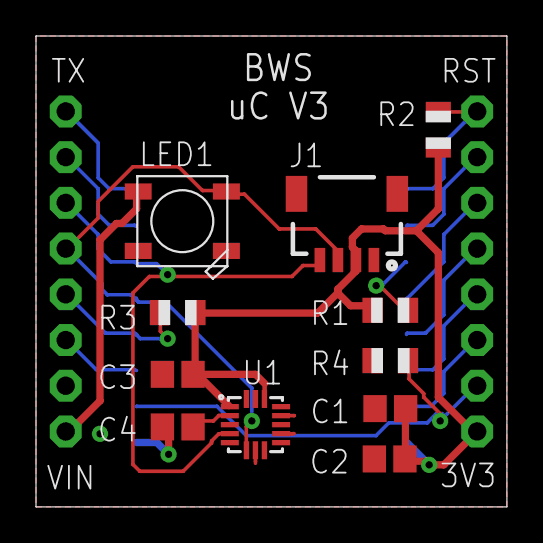
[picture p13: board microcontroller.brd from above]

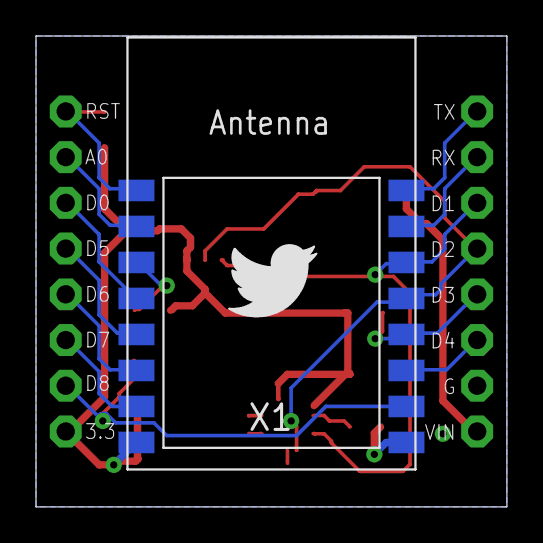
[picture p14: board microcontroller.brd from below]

Board: 2 copper layers, 26.2 x 26.2 mm, 15 parts (4 on the bottom side), 18 nets.

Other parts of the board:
U$1: TWITTER5MM

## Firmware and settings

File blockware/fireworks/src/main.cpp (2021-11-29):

// #define SERIALLOG 1
#include <DLog.h>

#include <Adafruit_SSD1351.h>
#include <SPI.h>
#include <math.h>

#include <Random.h>
#include <TLLogos.h>
#include <Text.h>
#include <Particle.h>
#include <DefaultConfig.h>

#include <LIS2DW12Sensor.h>
#include <optional>

const int tlWidth = 40;
const int tlHeight = 33;
const char *username = "@twitter";
const char *years = "5 years";


Adafruit_SSD1351 tft =
  Adafruit_SSD1351(SCREEN_WIDTH, SCREEN_HEIGHT, &SPI, CS_PIN, DC_PIN, RST_PIN);

std::vector<Particle> Particles;
std::optional<Particle> currRocket;

// in-memory 16-bit canvas
GFXcanvas16* canvas;
// screen dimensions
Vec2d<int> screen = Vec2d<int>();
const int FPS = floor(1000.0f / 30.0f); // (30fps)
uint16_t lastLoop = millis() - FPS + 1;

// logo position x,y
Vec2d<int> position = Vec2d<int>();
// years settings
uint8_t sizeYears = 2;
Vec2d<int> posVisYears = Vec2d<int>();
Vec2d<int> posHidYears = Vec2d<int>();
Vec2d<int> posYears = Vec2d<int>();
int yPosYears;
// username settings
uint8_t sizeUsername = 2;
Vec2d<int> posVisUsername = Vec2d<int>();
Vec2d<int> posHidUsername = Vec2d<int>();
Vec2d<int> posUsername = Vec2d<int>();
// text animation
float textAnimSpeed = 0.2f;
uint16_t textDisplayDuration = 10000;
uint16_t textCoolOffDuration = 1500;

// logo color animation
unsigned long lastLogoColorUpdate;
uint16_t sourceLogoColor = 0x0000;
uint16_t nextLogoColor = LOGO_BLUE;
uint16_t logoColorStep;
uint16_t defaultLogoColorSteps = 80;
uint16_t fastLogoColorSteps = 40;
uint16_t totalLogoColorSteps = defaultLogoColorSteps;

// Accelerometer
LIS2DW12Sensor* acc;
uint32_t accState;
bool wakeupText = true;
bool wakeupAll = true;
unsigned long lastWakeUpdate;
unsigned long lastTextEnabled;
unsigned long lastTextUpdate;
unsigned int wakeMaxDuration = 90000;

// NOTE: `loop`, `setup` and `flush` are sort of common operations
// Modify `initialize` and `tick` to customize this demo

void pickNextLogoColor() {
  if (wakeupAll && (nextLogoColor <= 0 || sourceLogoColor <= 0)) {
    nextLogoColor = std::max(sourceLogoColor, nextLogoColor);
    sourceLogoColor = 0x0000;
  }
  
  if (wakeupAll || nextLogoColor <= 0) {
    while(sourceLogoColor == nextLogoColor || nextLogoColor <= 0) {
      nextLogoColor = randomLogoColor();
    }
  } else {
    nextLogoColor = 0x0000;
  }
}

uint16_t getLogoColor() {
  // When asleep, only keep color logo on screen for 2s, otherwise 10s
  unsigned int onScreenTime = sourceLogoColor > 0 && !wakeupAll ? 2000 : 10000;
  
  // If we've just woken up, set logo color to animate in quickly
  if (wakeupAll && (nextLogoColor == 0 || sourceLogoColor == 0)) {
    uint16_t currStep = nextLogoColor == 0 ? (totalLogoColorSteps - logoColorStep) : logoColorStep;
    logoColorStep = (currStep * fastLogoColorSteps / totalLogoColorSteps) + 1; // Add 1 to make sure we animate
    totalLogoColorSteps = fastLogoColorSteps;
    pickNextLogoColor();
  }

  if (logoColorStep >= totalLogoColorSteps) {
    totalLogoColorSteps = defaultLogoColorSteps;
    sourceLogoColor = nextLogoColor;
    lastLogoColorUpdate = millis();
    logoColorStep = 0;
  } else if (logoColorStep > 0) {
    // Update color to next step
    logoColorStep += 1;
    return getColorMix(sourceLogoColor, nextLogoColor, totalLogoColorSteps, logoColorStep);
  } else if (millis() - lastLogoColorUpdate > onScreenTime) {
    // It's time to start animating the color change
    pickNextLogoColor();
    logoColorStep = 1;
  }

  return sourceLogoColor;
}

void drawLogo()
{
  uint16_t logoColor = getLogoColor();
  // Draw Logo 1 pixel at a time to allow changing the color
  int16_t larryStartY = (SCREEN_HEIGHT - tlHeight) / 2;
  int16_t larryStartX = (SCREEN_WIDTH - tlWidth) / 2;
  for (uint8_t y = 0; y < tlHeight; y++) {
    for (uint8_t x = 0; x < tlWidth; x++) {
      uint16_t color = ((uint16_t *)tl_blue)[y * tlWidth + x];
      if (color > 0) {
        uint16_t c = colorize(color, logoColor);
        canvas->drawPixel(larryStartX + x, larryStartY + y, c);
      }
    }
  }
}

void animateText(Vec2d<int> &posVec, Vec2d<int> &posVisVec, Vec2d<int> &posHidVec)
{
  int targetPos = wakeupText ? posVisVec.y : posHidVec.y;

  if (posVec.y != targetPos) {
    // lerp
    float nextPos = ((1.0f - textAnimSpeed) * posVec.y) + (textAnimSpeed * targetPos);

    // We need to call ceil or floor based on the relative direction of travel or we'll
    // never quite reach the target value.
    posVec.y = targetPos > posVec.y ? ceil(nextPos) : floor(nextPos);
  }
}

void drawText()
{
  animateText(posYears, posVisYears, posHidYears);
  animateText(posUsername, posVisUsername, posHidUsername);

  canvas->setTextColor(WHITE);

  canvas->setTextSize(sizeYears);
  canvas->setCursor(posYears.x, posYears.y);
  canvas->print(years);

  canvas->setTextSize(sizeUsername);
  canvas->setCursor(posUsername.x, posUsername.y);
  canvas->print(username);
}

void centerText(const char* text, Vec2d<int> &posVisVec, Vec2d<int> &posHidVec, uint8_t *size, int yTop, int yBottom)
{
  int16_t  x1, y1;
  uint16_t textWidth, textHeight;

  // start at size 2
  canvas->setTextSize(*size);
  canvas->getTextBounds(text, 0, 0, &x1, &y1, &textWidth, &textHeight);

  // text wider than screen? drop down to size 1
  if (textWidth > 100) {
    *size -= 1;
    canvas->setTextSize(*size);
    canvas->getTextBounds(text, 0, 0, &x1, &y1, &textWidth, &textHeight);
  }

  // center text
  int16_t textX = std::max(0, (int) floor(screen.x / 2 - textWidth / 2));
  int16_t textY = yTop + std::max(0, (int) floor((yBottom - yTop) / 2 - textHeight / 2));
  posVisVec.set(textX, textY);

  int16_t hidTextY = textY > (SCREEN_HEIGHT / 2) ? SCREEN_HEIGHT : 0 - textHeight;
  posHidVec.set(textX, hidTextY);
}

void drawParticles()
{
  if (!currRocket) {
    // random chance to add new firework if there's no rocket and particles count is below threshold
    if (wakeupAll && Particles.size() < 80 && randomf() <= 0.1) {
      currRocket = Particle(randomf() * screen.x, screen.y, true, randomFireworkColor());
    }
  } else if (currRocket.value().explode(Particles)) {
    // clear the optional rocket value once it's exploded, making room for another to be fired
    currRocket.reset();
  } else {
    // Tick and draw rocket
    Particle* rocket = &currRocket.value();
    rocket->tick();
    rocket->draw(canvas);
  }

  // Destroy old firework particles
  for (int i = (int) Particles.size() - 1; i >= 0; i--) {
    Particle* p = &Particles[i];
    if (p->destroy()) {
      Particles.erase(Particles.begin() + i);
    }
  }

  // Tick and draw firework particles
  for (int i = 0, max = (int) Particles.size(); i < max; i++) {
    Particle* p = &Particles[i];
    p->tick();
    p->draw(canvas);
  }
}

void updateWakeState(const int16_t (&accelAxes)[3])
{
  unsigned long now = millis();
  unsigned long timeSinceUpdate = now - lastWakeUpdate;

  if (timeSinceUpdate > wakeMaxDuration) {
    wakeupAll = false;
  }
  if (wakeupText && now - lastTextEnabled > textDisplayDuration) {
    lastTextUpdate = now;
    wakeupText = false;
  }

  // Scale accelerometer values down to be less sensitive
  uint32_t newAccState = (accelAxes[0] / 256 << 16) | (accelAxes[1] / 256 << 8) | accelAxes[2] / 256;

  // Update wake state
  bool changed = newAccState != accState;
  if (changed) {
    if (now - lastTextUpdate > textCoolOffDuration) {
      lastTextEnabled = now;
      wakeupText = true;
    }
    lastTextUpdate = now;
    wakeupAll = true;
    lastWakeUpdate = now;
    accState = newAccState;
  }
}

void updateGravity(const int16_t (&accelAxes)[3])
{
  Particle::updateGravity(Vec2d<float>(-accelAxes[0], -accelAxes[1]));
}

void readAccelerometer(int16_t (&accelAxes)[3])
{
  acc->Get_X_AxesRaw(accelAxes);
}

void initText()
{
  centerText(username, posVisUsername, posHidUsername, &sizeUsername, 0, position.y);
  centerText(years, posVisYears, posHidYears, &sizeYears, position.y + tlHeight, 128);
  posYears.x = posHidYears.x;
  posYears.y = posHidYears.y;
  posUsername.x = posHidUsername.x;
  posUsername.y = posHidUsername.y;
}

void flush()
{
  // write canvas to screen
  tft.drawRGBBitmap(0, 0, (uint16_t*)canvas->getBuffer(), screen.x, screen.y);
}

void initialize() {
  // reserve particles memory space
  Particles.reserve(EXPLOSION_PARTICLES * 2);

  // center logo
  position.set(floor(screen.x / 2 - tlWidth / 2), floor(screen.y / 2 - tlHeight / 2));

  // base
  initText();
  drawLogo();
  drawText();
}

void tick()
{
  // clear entire screen
  canvas->fillScreen(BLACK);

  // redraw entire canvas on every tick

  // base
  int16_t accelAxes[3];
  readAccelerometer(accelAxes);
  updateWakeState(accelAxes);
  updateGravity(accelAxes);
  drawParticles();
  drawLogo();
  drawText();
}

void loop()
{
  uint16_t now = millis();
  uint16_t time = now - lastLoop;

  //Serial.printf("frameMs=%d\n", time);
  //Serial.printf("FPS=%g\n", floor(1000.0f / (float)time));

  if (time > FPS) {
    // track loop millis to keep steady fps
    lastLoop = now;

    // run!
    tick();

    // flush our in-memory canvas to the screen
    flush();
  }
}

void setup(void)
{
  Serial.begin(SERIAL_DATA_RATE);
  tft.begin(SPI_SPEED);
  // initialize screen to black
  tft.fillScreen(BLACK);

  // save dimensions
  screen.x = tft.width();
  screen.y = tft.height();

  // initialize canvas to all black
  canvas = new GFXcanvas16(screen.x, screen.y);
  canvas->fillScreen(BLACK);

  // initialize srand
  randomSeed(ESP.getCycleCount());

  // setup accelerometer
  Wire.begin();
  acc = new LIS2DW12Sensor(&Wire, 0x31U);
  int begin_retval = acc->begin();
  Serial.printf("begin returned: %d\n", begin_retval);
  acc->Enable_X();
  // Max is 700000 in 160MHz mode and 400000 in 80MHz mode
  Wire.setClock(700000); // Run I2C at 700 KHz for faster screen updates

  // initialize contains demo specific setup
  initialize();

  flush();
}

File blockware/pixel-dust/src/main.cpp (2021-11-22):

#include <DefaultConfig.h>
// #define SERIALLOG 1
#include <DLog.h>
#include <Adafruit_SSD1351.h>
#include <SPI.h>
#include <Text.h>
#include <Adafruit_PixelDust.h>
#include <Colors.h>

// In 80MHz mode, we can do 100 grains at about 120FPS
// In 160MHz mode, we can do 100 grains at about 185FPS which feels nice

#define N_GRAINS    100 // Number of grains of sand
#define MAX_FPS     185 // Maximum redraw rate, frames/second
#define ELASTICITY  128 // Bounciness (0-255)

// Sand object, last 2 args are accelerometer scaling and grain elasticity
Adafruit_PixelDust sand(SCREEN_WIDTH, SCREEN_HEIGHT, N_GRAINS, 1, ELASTICITY);

Adafruit_SSD1351 tft = Adafruit_SSD1351(SCREEN_WIDTH, SCREEN_HEIGHT, &SPI, CS_PIN, DC_PIN, RST_PIN);

// Colors for each one of the grains
uint16_t colors[N_GRAINS];

typedef struct {
  dimension_t x;
  dimension_t y;
} point;
point grains[N_GRAINS];

// Twitter logo in blue
int larryWidth = 40;
int larryHeight = 33;
unsigned char larry[] = {
  0x00, 0x00, 0x00, 0x00, 0x00, 0x00, 0x00, 0x00, 0x00, 0x00, 0x00, 0x00, 0x00,
  0x00, 0x00, 0x00, 0x00, 0x00, 0x00, 0x00, 0x00, 0x00, 0x00, 0x00, 0x00, 0x00,
  0x00, 0x00, 0x00, 0x00, 0x00, 0x00, 0x00, 0x00, 0x00, 0x00, 0x00, 0x00, 0x00,
  0x00, 0x00, 0x00, 0x00, 0x00, 0x66, 0x00, 0xd4, 0x43, 0xfd, 0x1c, 0xfe, 0x1c,
  0x1d, 0x25, 0xdd, 0x1c, 0x1e, 0x1d, 0xfe, 0x1c, 0xfd, 0x1c, 0xfe, 0x1c, 0x00,
  0x00, 0x00, 0x00, 0x00, 0x00, 0x00, 0x00, 0x00, 0x00, 0x00, 0x00, 0xf3, 0x4b,
  0x66, 0x00, 0x00, 0x00, 0x00, 0x00, 0x35, 0x4c, 0x86, 0x00, 0x00, 0x00, 0x00,
  0x00, 0x00, 0x00, 0x00, 0x00, 0x00, 0x00, 0x00, 0x00, 0x00, 0x00, 0x00, 0x00,
  0x00, 0x00, 0x00, 0x00, 0x00, 0x00, 0x00, 0x00, 0x00, 0x00, 0x00, 0x00, 0x00,
  0x00, 0x00, 0x00, 0x00, 0x00, 0x00, 0x00, 0xbc, 0x14, 0xfd, 0x24, 0xfe, 0x1c,
  0x1d, 0x1d, 0xfe, 0x1c, 0x1d, 0x1d, 0xfe, 0x1c, 0x1d, 0x1d, 0xfe, 0x1c, 0x1d,
  0x1d, 0x56, 0x4c, 0x86, 0x00, 0x00, 0x00, 0x00, 0x00, 0xbc, 0x1c, 0xfc, 0x24,
  0x76, 0x4c, 0x86, 0x00, 0x86, 0x00, 0x76, 0x4c, 0x1d, 0x1d, 0xfe, 0x1c, 0x00,
  0x00, 0x00, 0x00, 0x00, 0x00, 0x00, 0x00, 0x00, 0x00, 0x00, 0x00, 0x00, 0x00,
  0x00, 0x00, 0x00, 0x00, 0x00, 0x00, 0x00, 0x00, 0x00, 0x00, 0x00, 0x00, 0x00,
  0x00, 0x00, 0x00, 0x00, 0x00, 0x87, 0x00, 0x97, 0x4c, 0x1e, 0x1d, 0x1e, 0x1d,
  0x1e, 0x1d, 0x1e, 0x1d, 0x1e, 0x1d, 0x1e, 0x1d, 0x1e, 0x1d, 0x1e, 0x1d, 0x1e,
  0x1d, 0x1e, 0x1d, 0x1e, 0x1d, 0xfe, 0x1c, 0x1e, 0x1d, 0x1e, 0x1d, 0x1e, 0x1d,
  0x1e, 0x1d, 0x55, 0x4c, 0x67, 0x00, 0x67, 0x00, 0x76, 0x54, 0xfe, 0x1c, 0x1d,
  0x1d, 0x97, 0x54, 0x87, 0x00, 0x00, 0x00, 0x00, 0x00, 0x00, 0x00, 0x00, 0x00,
  0x00, 0x00, 0x00, 0x00, 0x00, 0x00, 0x00, 0x00, 0x00, 0x00, 0x00, 0x00, 0x00,
  0x00, 0x00, 0x00, 0x00, 0x00, 0x00, 0x00, 0xbd, 0x1c, 0x1d, 0x25, 0xfe, 0x1c,
  0x1d, 0x1d, 0xfe, 0x1c, 0x1d, 0x1d, 0xfe, 0x1c, 0x1d, 0x1d, 0xfe, 0x1c, 0x1d,
  0x1d, 0xfe, 0x1c, 0x1d, 0x1d, 0xfe, 0x1c, 0x1d, 0x1d, 0xfe, 0x1c, 0x1d, 0x1d,
  0xfe, 0x1c, 0xfd, 0x1c, 0x00, 0x00, 0x00, 0x00, 0x87, 0x00, 0x77, 0x4c, 0x1e,
  0x1d, 0x1e, 0x1d, 0x1d, 0x1d, 0xfd, 0x1c, 0x00, 0x00, 0x00, 0x00, 0x00, 0x00,
  0x00, 0x00, 0x00, 0x00, 0x00, 0x00, 0x00, 0x00, 0x00, 0x00, 0x00, 0x00, 0x00,
  0x00, 0x00, 0x00, 0x00, 0x00, 0x00, 0x00, 0x00, 0x00, 0xfd, 0x1c, 0xfe, 0x1c,
  0x1e, 0x1d, 0x1e, 0x1d, 0x1e, 0x1d, 0x1e, 0x1d, 0x1e, 0x1d, 0x1e, 0x1d, 0x1e,
  0x1d, 0x1e, 0x1d, 0x1e, 0x1d, 0x1e, 0x1d, 0x1e, 0x1d, 0x1e, 0x1d, 0x1e, 0x1d,
  0x1e, 0x1d, 0xdc, 0x24, 0x7b, 0x14, 0xdc, 0x1c, 0xbc, 0x14, 0x67, 0x00, 0x76,
  0x54, 0xfe, 0x1c, 0x1d, 0x1d, 0xfe, 0x1c, 0x1d, 0x1d, 0x76, 0x4c, 0x86, 0x00,
  0x00, 0x00, 0x00, 0x00, 0x00, 0x00, 0x00, 0x00, 0x00, 0x00, 0x00, 0x00, 0x00,
  0x00, 0x00, 0x00, 0x00, 0x00, 0x00, 0x00, 0x67, 0x00, 0x76, 0x54, 0xfe, 0x1c,
  0x1d, 0x1d, 0xfe, 0x1c, 0x1d, 0x1d, 0xfe, 0x1c, 0x1d, 0x1d, 0xfe, 0x1c, 0x1d,
  0x1d, 0xfe, 0x1c, 0x1d, 0x1d, 0xfe, 0x1c, 0x1d, 0x1d, 0xfe, 0x1c, 0x1d, 0x1d,
  0xfe, 0x1c, 0x1d, 0x25, 0xfe, 0x1c, 0x1d, 0x1d, 0xfd, 0x24, 0x9b, 0x1c, 0x86,
  0x00, 0x77, 0x4c, 0x1e, 0x1d, 0x1e, 0x1d, 0x1e, 0x1d, 0x1e, 0x1d, 0x1e, 0x1d,
  0xfe, 0x1c, 0x97, 0x54, 0x87, 0x00, 0x00, 0x00, 0x00, 0x00, 0x00, 0x00, 0x00,
  0x00, 0x00, 0x00, 0x00, 0x00, 0x00, 0x00, 0x00, 0x00, 0x87, 0x00, 0x77, 0x4c,
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

// Accelerometer
#if defined(ACCEL_LIS2DW12)
#include <LIS2DW12Sensor.h>
#define ACCEL_ADDR 0x31U
LIS2DW12Sensor* accel;
#elif defined(ACCEL_MMA8452Q)
#include <SparkFun_MMA8452Q.h>
#define ACCEL_ADDR 0x1C
MMA8452Q accel(ACCEL_ADDR);
#endif

// Used for frames-per-second throttle
uint32_t prevTime = 0;

uint32_t frameCounter = 0;
uint32_t lastFrameMessage = 0;

int begin_retval;

void err(int x) {
  uint8_t i;
  pinMode(LED_BUILTIN, OUTPUT);       // Using onboard LED
  for(i=1;;i++) {                     // Loop forever...
    digitalWrite(LED_BUILTIN, i & 1); // LED on/off blink to alert user
    delay(x);
  }
}

void setup(void) {
  Wire.begin();

  if(!sand.begin()) err(1000); // Slow blink = malloc error

#if defined(ACCEL_LIS2DW12)
  accel = new LIS2DW12Sensor(&Wire, ACCEL_ADDR);
  // if (!accel->begin()) err(250);
  accel->Enable_X();
#elif defined(ACCEL_MMA8452Q)
  if (!accel.begin(Wire, ACCEL_ADDR)) err(250);
#endif

  Serial.begin(SERIAL_DATA_RATE);
  tft.begin(SPI_SPEED);

  // Max is 700000 in 160MHz mode and 400000 in 80MHz mode
  Wire.setClock(700000); // Run I2C at 700 KHz for faster screen updates

  // Clear the display
  displayReset();

  // Draw an obstacle for sand to move around
  dimension_t larryStartY = (SCREEN_HEIGHT - larryHeight) / 2;
  dimension_t larryStartX = (SCREEN_WIDTH - larryWidth) / 2;
  for (uint8_t y = 0; y < larryHeight; y++) {
    for (uint8_t x = 0; x < larryWidth; x++) {
      uint16_t color = ((uint16_t *)larry)[y * larryWidth + x];
      if (color > 0) {
        sand.setPixel(larryStartX + x, larryStartY + y);             // Set pixel in the simulation
      }
      tft.drawPixel(larryStartX + x, larryStartY + y, color);
    }
  }

  // Create some colors
  for (int i = 0; i < N_GRAINS; i ++) {
    colors[i] = randomColor();
  }

  sand.randomize(); // Initialize random sand positions

  lastFrameMessage = micros();
}
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

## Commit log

2019-09-18 Initial commit. Part of a schematic and pcb done.
    [blocks-with-screens.brd, blocks-with-screens.sch]
2019-09-18 Board updates
    [blocks-with-screens.brd, microcontroller.brd, microcontroller.sch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]
2019-09-18 oled board ready to be fab'd
    [oled.brd, oled.sch]
2019-09-18 microcontroller board ready to be fab'd
    [microcontroller.brd, microcontroller.sch]
2019-09-18 Add USB board layout
    Committing on master :)
    [usb.brd, usb.sch]
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2019-09-25 Link PCBs with Fusion360 design
    [microcontroller.brd, oled.brd, usb.brd]
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2019-09-26 added simple cache to throttle refresh of data
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2019-10-08 note to path to modify for MISO pin fix
    [main.cpp]
2019-10-10 README: fix miso pin and 90fps docs
2019-10-15 Fix qrcode include for case-sensitive file systems
    [main.cpp]
2019-10-15 Fix up some issues causing the build to fail in Travis
    [main.cpp]
2019-10-16 Rename WiFi->WifiHelper to prevent platformio from getting confused
    [main.cpp]
2019-10-22 USB board schematic V2 done
    [oled.brd, oled.sch, usb.brd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]
2019-10-22 V2 usb board ordered
    [usb.brd, usb.sch]
2019-10-22 Update fusion link
    [usb.brd]
2019-10-22 Rework Oled board to use VIN
    [oled.brd, oled.sch]
2019-10-22 V2 oled board ordered
    [oled.brd, oled.sch]
2019-10-22 Change 5V silkscreen to be VIN on OLED board
    [oled.brd]
2019-10-22 Add a bunch of manufacturer part numbers to OLED board
    [oled.brd, oled.sch]
2019-10-22 Use GPIO2 instead of GPIO5(SCL) for OLED DC pin
    [oled.brd, oled.sch]
2019-10-22 Add manufacturer part numbers to USB board
    [usb.brd, usb.sch]
2019-10-22 Mark a trace as power in the USB board
    [usb.brd, usb.sch]
2019-10-22 Add a pcb/README.md with details about board changes
2019-10-23 Microcontroller v2 pcb ordered
    [microcontroller.brd, microcontroller.sch]
2019-10-23 Mark updated usb v3 board (ordered)
    [usb.brd]
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2019-10-23 Oled board v3 ordered
    [oled.brd, oled.sch]
2019-10-23 Add part numbers for the headers on the usb board
    [usb.brd, usb.sch]
2019-10-25 Use cheaper 0.1uF capacitors and 10uF capacitors
    [microcontroller.brd, microcontroller.sch, oled.brd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]
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2020-06-26 Use POWER net class (thicker trace) for 3.3V in USB board
    [usb.brd, usb.sch]
2020-06-26 Add jumper to bypass switch on USB board
    [usb.brd, usb.sch]
2020-06-26 Make the slots for the usb connector wider
    [usb.brd, usb.sch]
2020-06-27 Fix microcontroller board to actually connect 3.3V to the microcontroller
    [microcontroller.brd, microcontroller.sch]
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2020-06-30 Remove switch bypass jumper (revert c81c233)
    [usb.brd, usb.sch]
2020-06-30 Add a jst-sh battery connector
    [usb.brd, usb.sch]
2020-06-30 Bump USB board silkscreen to V4
    [usb.brd]
2020-06-30 Fix up some silkscreen and wire stubs on usb board
    [usb.brd]
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2020-06-30 Center battery connector at top of usb board
    [usb.brd]
2020-07-01 Update 3d model links for oled and usb board
    [oled.brd, oled.sch, usb.brd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]
2020-07-01 Headers were on the wrong side on the usb board
    [usb.brd]
2020-07-01 Fix 3d models for microcontroller board
    [microcontroller.brd, microcontroller.sch]
2020-07-01 Fix header direction on microcontroller board
    [microcontroller.brd]
2020-07-02 Rotate switch so that pin numbering matches orientation from the datasheet
    [usb.brd, usb.sch]
2020-07-02 change populate field for some parts
    [microcontroller.brd, microcontroller.sch]
2020-07-02 added thru-hole parameters and updated eagle export script
    [microcontroller.brd, microcontroller.sch]
2020-07-02 added thru-hole prop to usb board
    [usb.brd, usb.sch]
2020-07-02 added bottom prop to usb connector
    [usb.brd, usb.sch]
2020-07-02 added populate attr
    [usb.brd, usb.sch]
2020-07-02 changed some part numbers
    [usb.brd, usb.sch]
2020-07-02 replaced 0805 10k with 0603
    [usb.brd, usb.sch]
2020-07-02 added MPN for jst connector
    [usb.brd, usb.sch]
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2020-07-04 Add rgb-accelerometer demo and make a lot of demos use DefaultConfig.h
2020-07-04 Use GitHub Actions instead of Travis (#11)
    * Use python3 platformio
    * Add a github action
    * Try to add Wire manually
    * Add Wire to all the things
    * Add Adafruit_GFX.h explicitly to jpeg-download so that it gets the min/max defines
    * Try defining max/min
    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
2020-07-07 updated part number for usb connector
    [usb.brd, usb.sch]
2020-07-08 added 8 pin header part number
    [usb.brd, usb.sch]
2020-07-09 updated part numbers
    [microcontroller.brd, microcontroller.sch]
2020-07-09 changed part number for pin header on oled board
    [oled.brd, oled.sch]
2020-07-10 Revert OLED board to use 3.3V for input to the 13V FAN5331 boost
    [oled.brd, oled.sch]
2020-07-10 changed 590k resistor to 620k
    [oled.brd, oled.sch]
2020-08-29 USB pcb V5 - turn battery connector 90 deg
    [usb.brd, usb.sch]
2020-11-17 Update main README.md and the ones for the blockware and pcbs
2020-11-21 Fix comment about hacking SPI on OLED V1 boards
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2020-12-02 Add CAD files
    [puzzleblock.f3d]
2020-12-02 Move pcb under cad
    [.csv, microcontroller.brd, microcontroller.sch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]
2021-03-16 updated R2 and R4 values, changed 3.3v regulator to AP2112K-3.3
    [usb.brd, usb.sch]
2021-03-16 Revert "Revert OLED board to use 3.3V for input to the 13V FAN5331 boost"
    This reverts commit 2f54354309870ccb091a2a633caf6ab9d6db30ca.
    [oled.brd, oled.sch]
2021-03-16 Change reverted OLED to V5. Small GND trace cleanup.
    [oled.brd]
2021-03-16 added POPULATE to usb thru hole parts
    [usb.brd, usb.sch]
2021-03-16 fixed part number
    [usb.brd, usb.sch]
2021-03-16 renamed yellow led to white
    [usb.brd, usb.sch]
2021-05-05 replace C2,C3,C4,C6 on oled board with CL21A106KOQNNNE (10uF,16V)
    [oled.brd, oled.sch]
2021-06-04 added kicad files for microcontroller board v4
    [microcontroller.kicad_pcb, microcontroller.sch]
2021-10-16 Fix the fireworks blockware
    [main.cpp]
2021-10-18 Untested API migrations to work with the latest esp arduino libs
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2021-11-06 Use johnboiles AdafruitGFX fork
    While we wait for https://github.com/adafruit/Adafruit-GFX-Library/pull/370 to get merged.
    This also removes the 90fps example since it's no longer as relevant.
    [90fps.cpp, main.cpp]
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2021-11-08 Mhill/lisdw12 accel (#5)
    * messy changes to make LISDW12 accelerometer work with pixel-dust
    * moved lis2dw12 files to lib
    * removed unused accelerometer code
    * set up LIS2DW12 as dependency
2021-11-16 Keep (disabled-by-default) configs for MMA8452Q accelerometer for old blocks (#6)
2021-11-17 Add Driver install instructions for Windows
    - Fixes #8
2021-11-17 Fixes to reintroduce some recent changes
    [main.cpp]
2021-11-20 🛠️ build(update): make update and docs
    Ensure PlatformIO is up to date.
    This fixes an issue where the toolchain was not able to build c++17
    which is required in some Blockware now (see blockware/fireworks)
2021-11-22 🐛fix(pixel-dust): accel->begin returns false always
    [main.cpp]
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2021-11-24 Virtualblox accel support (#17)
    * Fix the build
    * VirtualBlox support for LIS2DW12 accelerometer
    * Go back to c++17
    [main.cpp]
2021-11-25 📦feat(VirtualBlox): use UTF8 fork of Adafruit_GFX lib (#18)
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2021-11-27 ✨feat(matrix) blockware/matrix
    forked adafruit gfx with utf 8 support
    fixed build errors by copying from johnboiles fork
    generated a subset of unifont into program memory
    blockware/matrix/.pio/libdeps/esp12e/Adafruit GFX Library UTF8/glcdfont.c
    japanese characters now work! 🎉
    [main.cpp]
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2021-11-27 🐛fix(FPS): correct FPS logic
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2021-11-29 🐛fix(Matrix): int x,y float overlap?
2021-11-29 🐛fix(Matrix): include edge overflow
2021-11-29 Fireworks: Accelerometer-driven gravity (#14)
    * Accelerometer-driven gravity
    * Read acclerometer just once
    * camelCase
2022-01-06 ESP32-PICO-D4 based microcontroller board (#13)
    [microcontroller-esp32.brd, microcontroller-esp32.sch]

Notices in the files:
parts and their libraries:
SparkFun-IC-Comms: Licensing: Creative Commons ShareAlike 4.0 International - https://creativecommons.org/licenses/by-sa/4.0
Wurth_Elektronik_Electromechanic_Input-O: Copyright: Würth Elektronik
